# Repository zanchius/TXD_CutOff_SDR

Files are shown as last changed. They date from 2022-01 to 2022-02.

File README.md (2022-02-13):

# TXD_CutOff_SDR
A FET/Relay based RF/TXD cutoff switch to protect SDR receivers which share the same antenna with a transceiver.
Input signal from the transceiver, in this case a Yaesu FT-991A is taken from the SQL pin on the Data port miniDIN 6 pins socket, as it's on a HIGH 5V level during RX and LOW 0V on TX.
The relay is constantly energised with the HIGH signal and will disconnect the SDR under a LOW signal.

Partlist in the repository

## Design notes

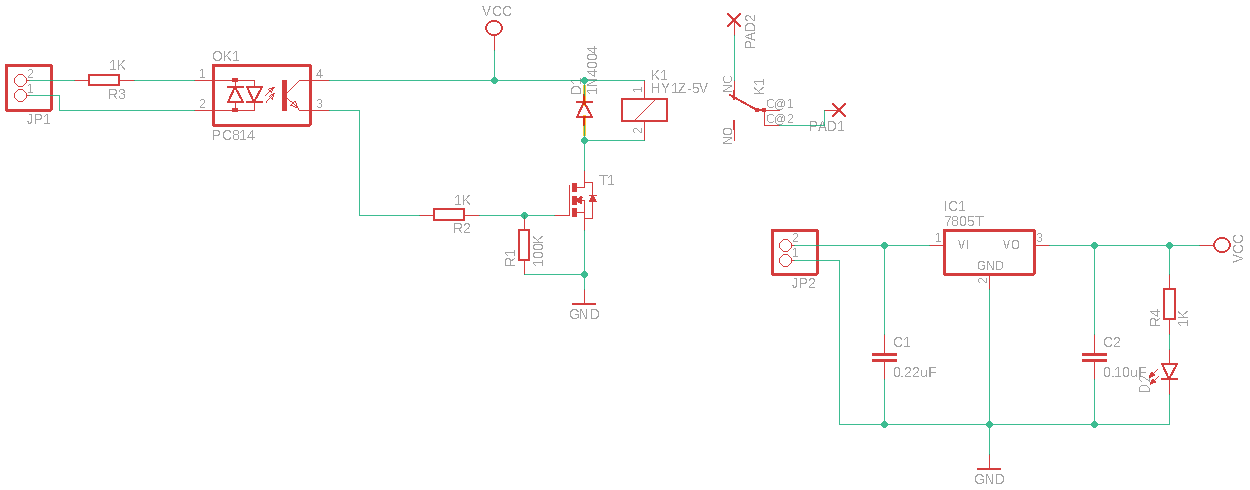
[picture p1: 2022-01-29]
sdr_cutoff.png

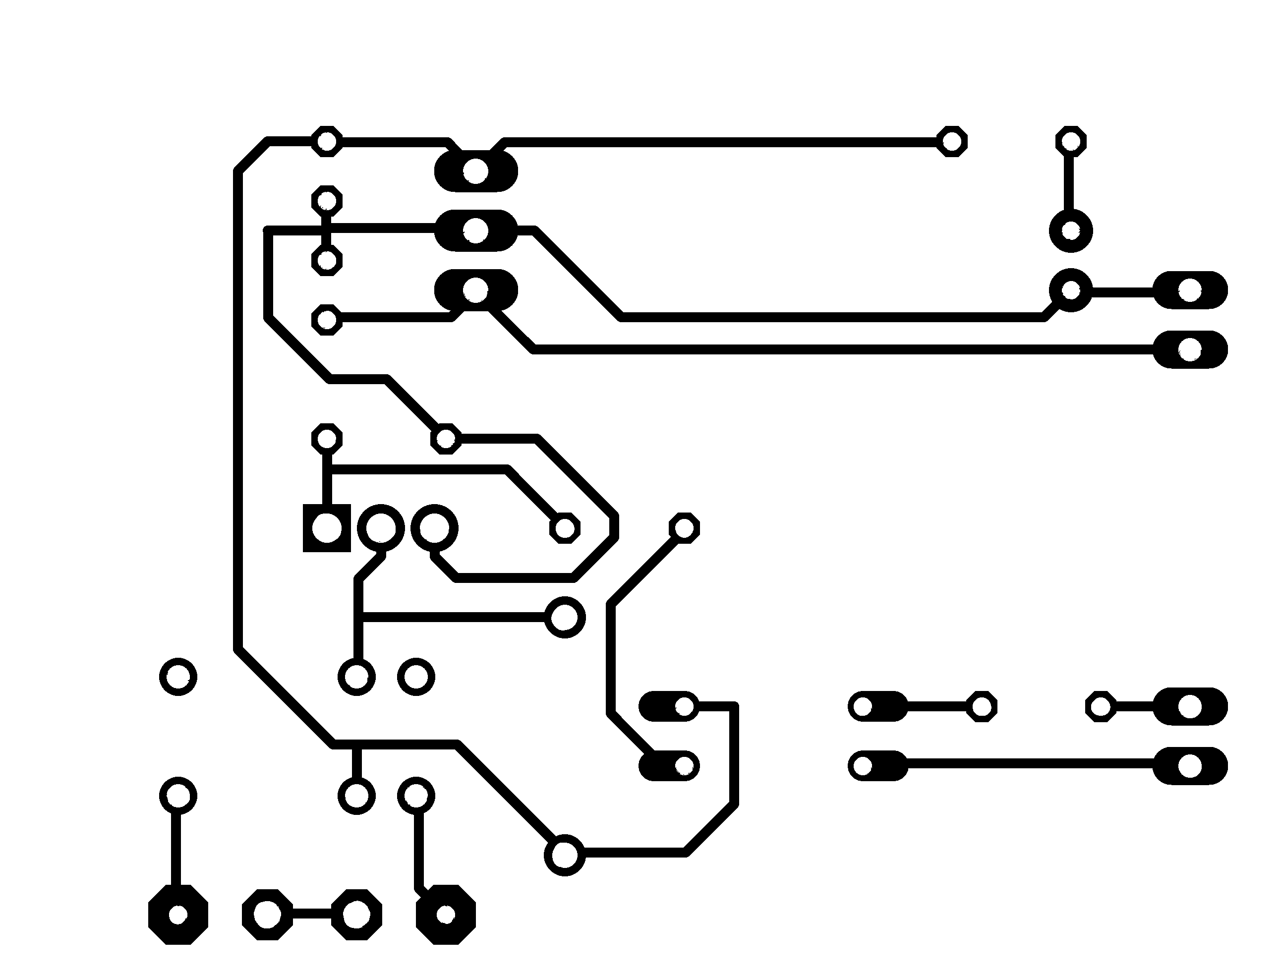
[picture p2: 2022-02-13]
sdr_cutoff_pcb.png

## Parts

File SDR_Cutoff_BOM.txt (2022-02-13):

Partlist

Exported from sdr_cutoff.sch at 13/02/2022 11:55

EAGLE Version 9.6.2 Copyright (c) 1988-2020 Autodesk, Inc.

Assembly variant: 

Part     Value          Device          Package              Library      Sheet

+DCIN-                  PINHD-1X2       1X02                 pinhead      1
C1       0.22uF         C-EU025-024X044 C025-024X044         rcl          1
C2       0.10uF         C-EU025-024X044 C025-024X044         rcl          1
D1       1N4004         1N4004          DO41-10              diode        1
D2                      LED3MM          LED_3MM              SparkFun-LED 1
IC1      7805T          7805T           TO220H               linear       1
K1       HY1Z-5V        HY1Z-5V         HY                   relay        1
OK1      PC814          PC814           DIL04                optocoupler  1
R1       100K           R-EU_0204/5     0204/5               rcl          1
R2       1K             R-EU_0204/5     0204/5               rcl          1
R3       1K             R-EU_0204/5     0204/5               rcl          1
R4       1K             R-EU_0204/5     0204/5               rcl          1
RFGND1   MCS08          MCS08           MCS08                solpad       1
RFGND2   MCS08          MCS08           MCS08                solpad       1
RFIN                    2,54/0,8        2,54/0,8             wirepad      1
RFOUT                   2,54/0,8        2,54/0,8             wirepad      1
SQLTRIG                 PINHD-1X2       1X02                 pinhead      1
T1       RFD14N05L      RFD14N05L       TO229P250X658X985-3P RFD14N05L    1

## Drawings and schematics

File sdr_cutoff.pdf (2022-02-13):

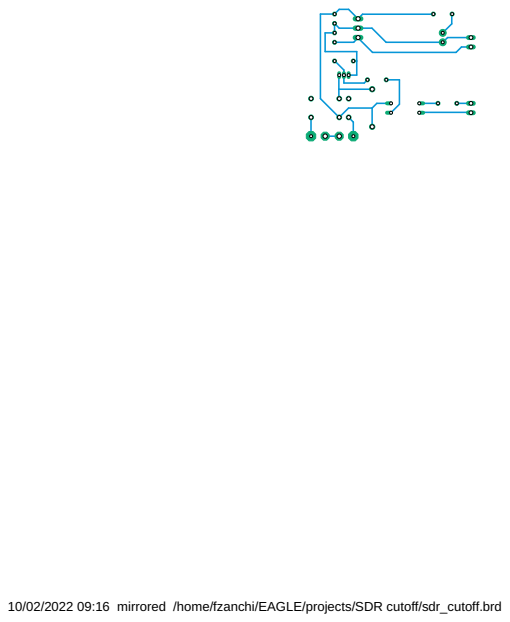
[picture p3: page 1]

10/02/2022 09:16 mirrored /home/fzanchi/EAGLE/projects/SDR cutoff/sdr_cutoff.brd

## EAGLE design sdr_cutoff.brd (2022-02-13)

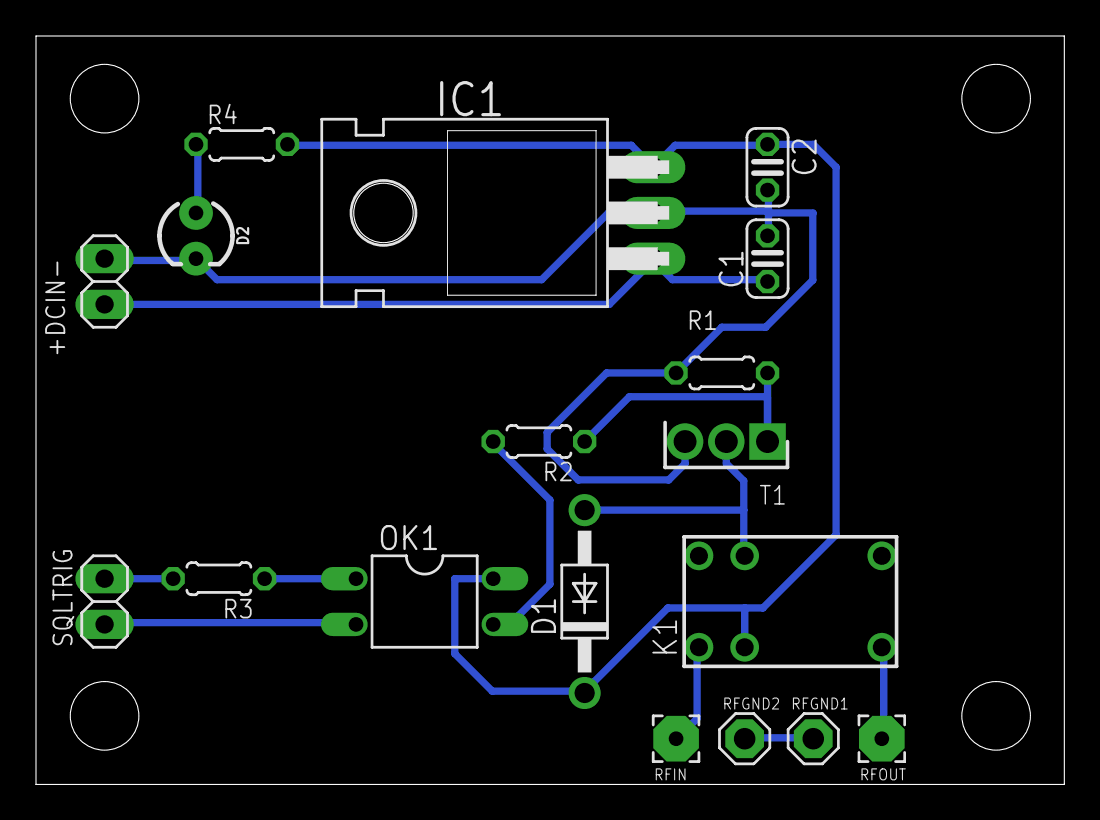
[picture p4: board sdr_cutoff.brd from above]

Board: 2 copper layers, 57.1 x 41.6 mm, 18 parts (0 on the bottom side), 13 nets.

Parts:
+DCIN-: 1X02
C1: 0.22uF; C025-024X044
C2: 0.10uF; C025-024X044
D1: 1N4004; DO41-10
D2: LED_3MM
IC1: 7805T; TO220H
K1: HY1Z-5V; HY
OK1: PC814; DIL04
R1: 100K; 0204/5
R2, R3, R4: 1K; 0204/5
RFGND1, RFGND2: MCS08
RFIN: 2,54/0,8
RFOUT: 2,54/0,8
SQLTRIG: 1X02
T1: RFD14N05L; TO229P250X658X985-3P

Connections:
GND: +DCIN-.1, C1.2, C2.2, D2.K, IC1.2, R1.1, T1.3
unnamed: D1.A, K1.2, T1.2
unnamed: OK1.3, R2.2
unnamed: R1.2, R2.1, T1.1
unnamed: OK1.1, R3.1
unnamed: OK1.2, SQLTRIG.1
unnamed: R3.2, SQLTRIG.2
unnamed: RFGND1.MP, RFGND2.MP
unnamed: +DCIN-.2, C1.1, IC1.1
unnamed: K1.NC, RFIN.1
unnamed: D2.A, R4.1
unnamed: K1.C@2, RFOUT.1
VCC: C2.1, D1.C, IC1.3, K1.1, OK1.4, R4.2

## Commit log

2022-01-29 Add files via upload
    Corrected missing ground on DC block
    [sdr_cutoff.brd, sdr_cutoff.sch]
2022-02-13 Add files via upload
    Corrected minor errors and finalised PCB layout
    [sdr_cutoff.brd]

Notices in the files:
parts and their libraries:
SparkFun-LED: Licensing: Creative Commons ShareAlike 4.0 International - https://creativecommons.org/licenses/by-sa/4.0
